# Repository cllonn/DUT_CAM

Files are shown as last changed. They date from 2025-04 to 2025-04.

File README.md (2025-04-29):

# DUT_CAM Camera Board Project
PCB designed to interface a camera module with the Atlas board to provide standalone testing for future design

## Project Overview
This board is a camera testing board that uses an OV2640 camera signals to an ESP32-S3, adds microSD storage, and includes USB-C power input with LDOs. Mainly used as a verificationnn board for later Atlas integration.

## Features
- **USB-C Power Input**: 5 V via USB-C connector
- **Power Regulation**:
  - 3.3 V LDO for ESP32-S3 and camera core
  - 2.8 V LDO for camera I/O
  - 1.2 V LDO for camera I/O
- **Camera Sensor Interface**:
  - 24-pin FPC footprint for OV2640
  - I²C (SDA/SCL) and parallel data bus (D0–D7) breakout
- **Microcontroller Footprint**: ESP32-S3-WROOM-1-N8R8 for on-board firmware testing
- **MicroSD Card Slot**: Store captured images or log data locally

## Block Diagram
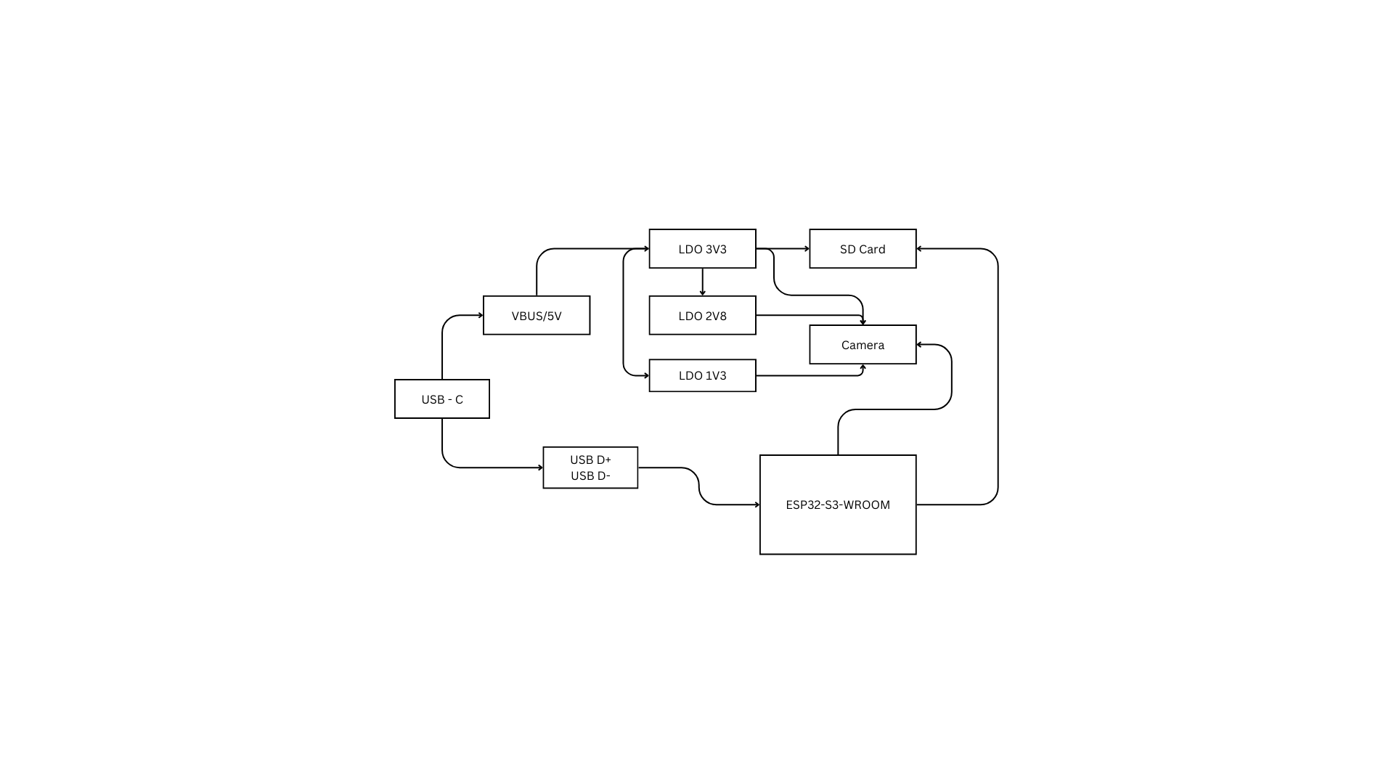
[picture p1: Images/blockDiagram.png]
Block Diagram


## Circuit Schematic
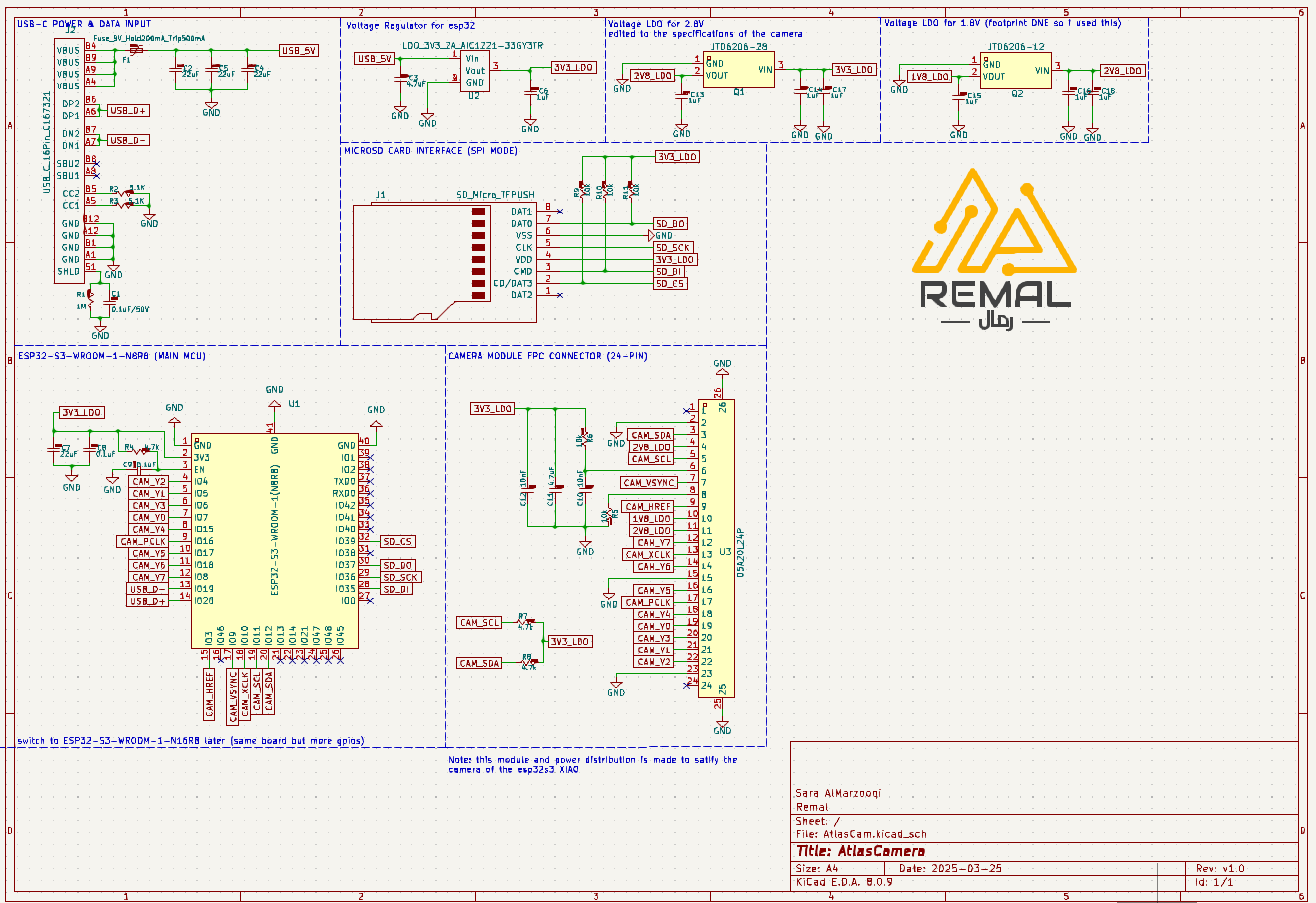
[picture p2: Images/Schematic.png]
Circuit Schematic


## PCB Layout
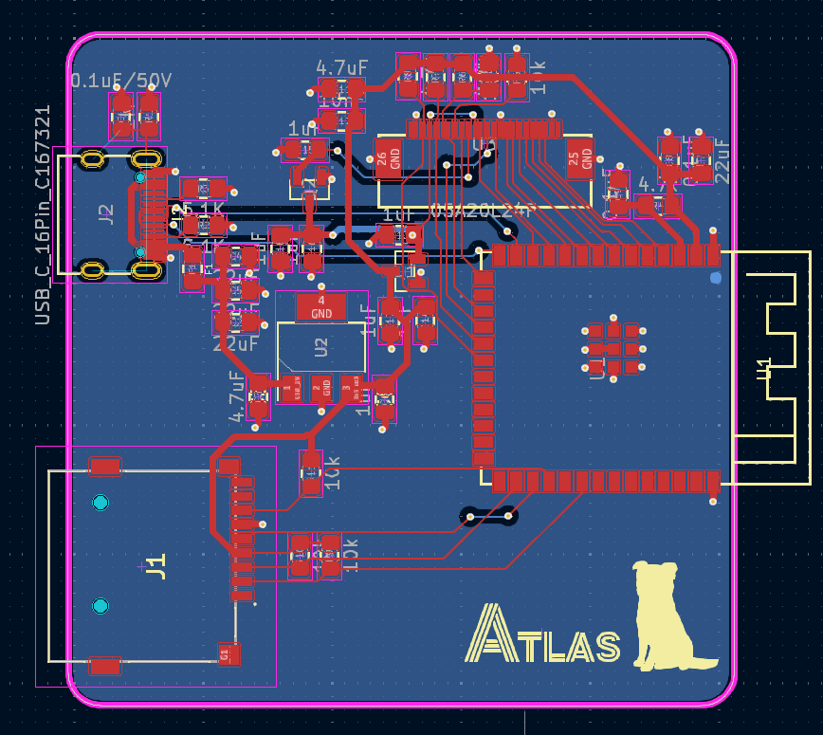
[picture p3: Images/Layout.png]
PCB Layout


## Usage
1. Insert a microSD card into the slot.
2. Flash and run code written for the board.
3. Open the serial monitor and note the IP address the board prints.
4. In your web browser, navigate to `http://<board_ip>/`.
5. Enjoy the live video stream.

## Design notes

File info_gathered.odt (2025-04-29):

Upgrading Atlas to feature a camera

Microcontroller chosen: ESP32-S3-WROOM-1-N8R8

Datasheet: https://www.lcsc.com/datasheet/lcsc_datasheet_2411121101_Espressif-Systems-ESP32-S3-WROOM-1-N8R8_C2913201.pdf

XIAO-ESP32S3 Sense:

Link to ebook: https://mjrovai.github.io/XIAO_Big_Power_Small_Board-ebook/

Specification:

Processor: ESP32-S3R8, Xtensa LX7 dual-core, 32-bit processor that operates at up to 240 Mhz

Wireless: Complete 2.4GHz Wi-Fi subsystem; BLE: Bluetooth 5.0, Bluetooth mesh

Built-in Sensors: OV2640 camera sensor for 1600*1200; Digital microphone

Memory: On-chip 8M PSRAM & 8MB Flash; Onboard SD Card Slot, supporting 32GB FAT

Interface: 1x UART, 1x IIC, 1x IIS, 1x SPI, 11x GPIOs (PWM), 9x ADC, 1x User LED, 1x Charge LED, 1x B2B Connector (with 2 additional GPIOs), 1x Reset button, 1x Boot button

Dimentions: 21 x 17.8 x 15mm (with expansion board)

Power:- Input voltage (Type-C): 5V; Input voltage (BAT): 4.2V

- Circuit operating Voltage (ready to operate):
- Type-C: 5V@38.3mA
- BAT: 3.8V@43.2mA (with expansion board)

- Webcam Web application:
- Type-C:
- Average power consumption: 5V/138mA
- Photo moment: 5V/341mA
- Battery:
- Average power consumption: 3.8V/154mA
- Photo moment: 3.8V/304mA

- Microphone recording & SD card writing:
- Type-C:
- Average power consumption: 5V/46.5mA
- Peak power consumption: 5V/89.6mA
- Battery:
- Average power consumption: 3.8V/54.4mA
- Peak power consumption: 3.8V/108mA

- Charging battery current: 100mA

Low Power Consumption Model:

- Without any peripherals:
- Modem-sleep Model: 3.8V/25.5 mA
- Light-sleep Model: 3.8V/2.4 mA
- Deep Sleep Model: 3.8V/63.768 μA
- Connect the camera:
- Modem-sleep Model: 3.8V/44.57 mA
- Light-sleep Model: 3.8V/5.47 mA
- Deep Sleep Model: 3.8V/3.00 mA
- Connecting an SD Card:
- Modem-sleep Model: 3.8V/32.8 mA
- Light-sleep Model: 3.8V/3.48 mA
- Deep Sleep Model: 3.8V/1.08 mA
- Simultaneously connect the camera and the SD card:
- Modem-sleep Model: 3.8V/55.72 mA
- Light-sleep Model: 3.8V/6.56 mA
- Deep Sleep Model: 3.8V/3.98 mA

Wi-Fi Enabled Power Consumptionnn: ~110 mA

BLE Enabled Power Connnnnnnsumptionnnnnnnnnnn: ~102 mA

Pins needed for camera: 14

- 1 XMCLK

- 8 Y#

- 1 PCLK

- 2 I2C (SDA, SCL)

- 1 VSYNC

- 1 HREF

Pins needed f MicroSD: 4 -> Atlas already has MicroSD slot that is counted for

Pins needed for MIC: 2 -> We dont want a mic do ignore.

Schematic and Layout of XIAO-ESP32-S3 Sense (https://wiki.seeedstudio.com/xiao_esp32s3_getting_started/#for-seeed-studio-xiao-esp32s3-sense)

- [PDF] Seeed Studio XIAO ESP32S3 Sense Schematic (https://files.seeedstudio.com/wiki/SeeedStudio-XIAO-ESP32S3/res/XIAO_ESP32S3_ExpBoard_v1.0_SCH.pdf)
- [Ebook] XIAO: Big Power, Small Board Mastering Arduino and TinyML (https://mjrovai.github.io/XIAO_Big_Power_Small_Board-ebook/)
- [ZIP] Seeed Studio XIAO ESP32S3 Sense KiCAD Libraries (https://files.seeedstudio.com/wiki/SeeedStudio-XIAO-ESP32S3/res/Seeeduino-xiao-ESP32S3-KiCAD-Library.zip)
- [ZIP] Seeed Studio XIAO ESP32S3 Sense Eagle Libraries (https://files.seeedstudio.com/wiki/SeeedStudio-XIAO-ESP32S3/res/XIAO_ESP32S3_ExpBoard_v1.0_SCH&PCB_230324.zip)
- [DXF] Seeed Studio XIAO ESP32S3 Sense Dimension in DXF (top) (https://files.seeedstudio.com/wiki/SeeedStudio-XIAO-ESP32S3/res/XIAO_ESP32S3_ExpBoard_v1.0_top.dxf)
- [DXF] Seeed Studio XIAO ESP32S3 Sense Dimension in DXF (bottom) (https://files.seeedstudio.com/wiki/SeeedStudio-XIAO-ESP32S3/res/XIAO_ESP32S3_ExpBoard_v1.0_bot.dxf)
- [ZIP] Seeed Studio XIAO ESP32S3 Sense Factory firmware (https://files.seeedstudio.com/wiki/SeeedStudio-XIAO-ESP32S3/res/XIAO-ESP32S3-Sense-firmware-20240814.zip)
- [XLSX] Seeed Studio XIAO ESP32S3 Sense pinout sheet (https://files.seeedstudio.com/wiki/SeeedStudio-XIAO-ESP32S3/res/XIAO_ESP32S3_Sense_Pinout.xlsx)
- [STEP] Seeed Studio XIAO ESP32S3 Sense 3D Model (https://files.seeedstudio.com/wiki/SeeedStudio-XIAO-ESP32S3/res/seeed-studio-xiao-esp32s3-sense-3d_model.zip)
- 🔗 [Kicad] Seeed Studio XIAO ESP32S3 Sense FootPrint (https://github.com/Seeed-Studio/OPL_Kicad_Library/tree/master/Seeed%20Studio%20XIAO%20Series%20Library)

And for the bottom layer (XIAO ESP32-S3) (https://wiki.seeedstudio.com/xiao_esp32s3_getting_started/#for-seeed-studio-xiao-esp32s3)

- [PDF] Seeed Studio XIAO ESP32S3 Schematic (https://files.seeedstudio.com/wiki/SeeedStudio-XIAO-ESP32S3/res/XIAO_ESP32S3_SCH_v1.2.pdf)
- [ZIP] Seeed Studio XIAO ESP32S3 Eagle Libraries (https://files.seeedstudio.com/wiki/SeeedStudio-XIAO-ESP32S3/res/XIAO_ESP32S3_v1.1_SCH&PCB_230327.zip)
- [DXF] Seeed Studio XIAO ESP32S3 Dimension in DXF (https://files.seeedstudio.com/wiki/SeeedStudio-XIAO-ESP32S3/res/XIAO_ESP32S3_v1.1_Dimensioning.dxf)
- [LBR] Seeed Studio XIAO ESP32S3 Eagle footprint (https://files.seeedstudio.com/wiki/SeeedStudio-XIAO-ESP32S3/res/Seeed-Studio-XIAO-ESP32S3-footprint-eagle.lbr)
- [ZIP] Seeed Studio XIAO ESP32S3 Factory firmware (https://files.seeedstudio.com/wiki/SeeedStudio-XIAO-ESP32S3/res/XIAO-ESP32S3-firmware-20240814.zip)
- [XLSX] Seeed Studio XIAO ESP32S3 pinout sheet (https://files.seeedstudio.com/wiki/SeeedStudio-XIAO-ESP32S3/res/XIAO_ESP32S3_Sense_Pinout.xlsx)
- [STEP] Seeed Studio XIAO ESP32S3 3D Model (https://files.seeedstudio.com/wiki/SeeedStudio-XIAO-ESP32S3/res/seeed-studio-xiao-esp32s3-3d_model.zip)
- [ZIP] Seeed Studio XIAO ESP32S3 Certification files (https://files.seeedstudio.com/wiki/SeeedStudio-XIAO-ESP32S3/res/XIAO_ESP32S3_Certification.zip)
- 🔗 [Kicad] Seeed Studio XIAO ESP32S3 FootPrint (https://github.com/Seeed-Studio/OPL_Kicad_Library/tree/master/Seeed%20Studio%20XIAO%20Series%20Library)

ESP32_CAM_S

Link to schematic: file:///home/sara/Desktop/CameraResearch/esp32_cam_sch.pdf

Pins needed for camera: 14

- 8 Y# -> 8-bit parallel pixel data

- 1 MCLK ->External clock input from ESP32 to run its internal logic

- 1 PCLK ->Pixel clock. Tells ESP32 when to read the D0–D7 pins

- 2 I2C (SDA, Sck) -> SDA:Used to configure camera settings (brightness, etc)

-> SCL:Clock line for camera configuration

- 1 VSYNC ->Vertical sync

- 1 HSYNC ->Horizontal reference

Pins needed f MicroSD: 4 -> Atlas already has MicroSD slot that is counted for

[VSYNC] -> Start of Frame

[HREF] -> Start of Row

[PCLK] -> New Byte on D0-D7:

D0-D7: 10010110

D0-D7: 11000110

[HREF] Ends -> End of Row

[VSYNC] Ends -> End of Frame

Comparision list

Feature | XIAO ESP32S3 | AI-Thinker ESP32-CAM
Chip | ESP32-S3R8 (dual-core LX7) | ESP32 (dual-core LX6)
Flash Memory | 8MB | 4MB
PSRAM | 8MB | 4MB
Camera Sensor | OV2640 built-in (on expansion board) | OV2640 built-in
Max Camera Resolution | 1600×1200 (UXGA) | 1600×1200 (UXGA)
SD Card Slot | Onboard (up to 32GB FAT) | Built-in
Microphone | Digital mic onboard (I2S) | Not included
Battery Support | Contains mountable battery space and recharge | Vin, gnd – no recharge
Wi-Fi | Wi-Fi 4 (802.11 b/g/n) | Wi-Fi 4 (802.11 b/g/n/e/i)
Bluetooth | Bluetooth 5.0 + Mesh | Bluetooth 4.2
USB | Native USB-C (no programmer needed) | Requires external USB-to-Serial adapter
GPIOs (usable) | ~11 GPIOs (PWM capable), +2 via B2B connector | 9 GPIOs (shared with camera/sd)
Programming & Debugging | Simple: USB-C | Requires external programmer
Camera Interface | Native parallel (LCD_CAM peripheral) | GPIO-based (bit-banged style)
Power Supply | 5V via USB-C or 4.2V battery | 5V via header
Wi-Fi ON | ~110mA | ~180mA wif flash OFF
Camera + SD (Photo Moment) | 304–341mA peak | 310mA with flash ON
Deep Sleep (no peripherals) | 63.8 µA | ~6mA
Camera + SD (Deep Sleep) | ~4mA | Not specified but likely ~6–10mA
Charging Current (USB-C) | 100mA | Not built-in

Camera is not available at the lcsc but i found it on alibaba

https://www.alibaba.com/product-detail/Mini-OV2640-2-Million-Pixel-Wide_1601278159929.html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

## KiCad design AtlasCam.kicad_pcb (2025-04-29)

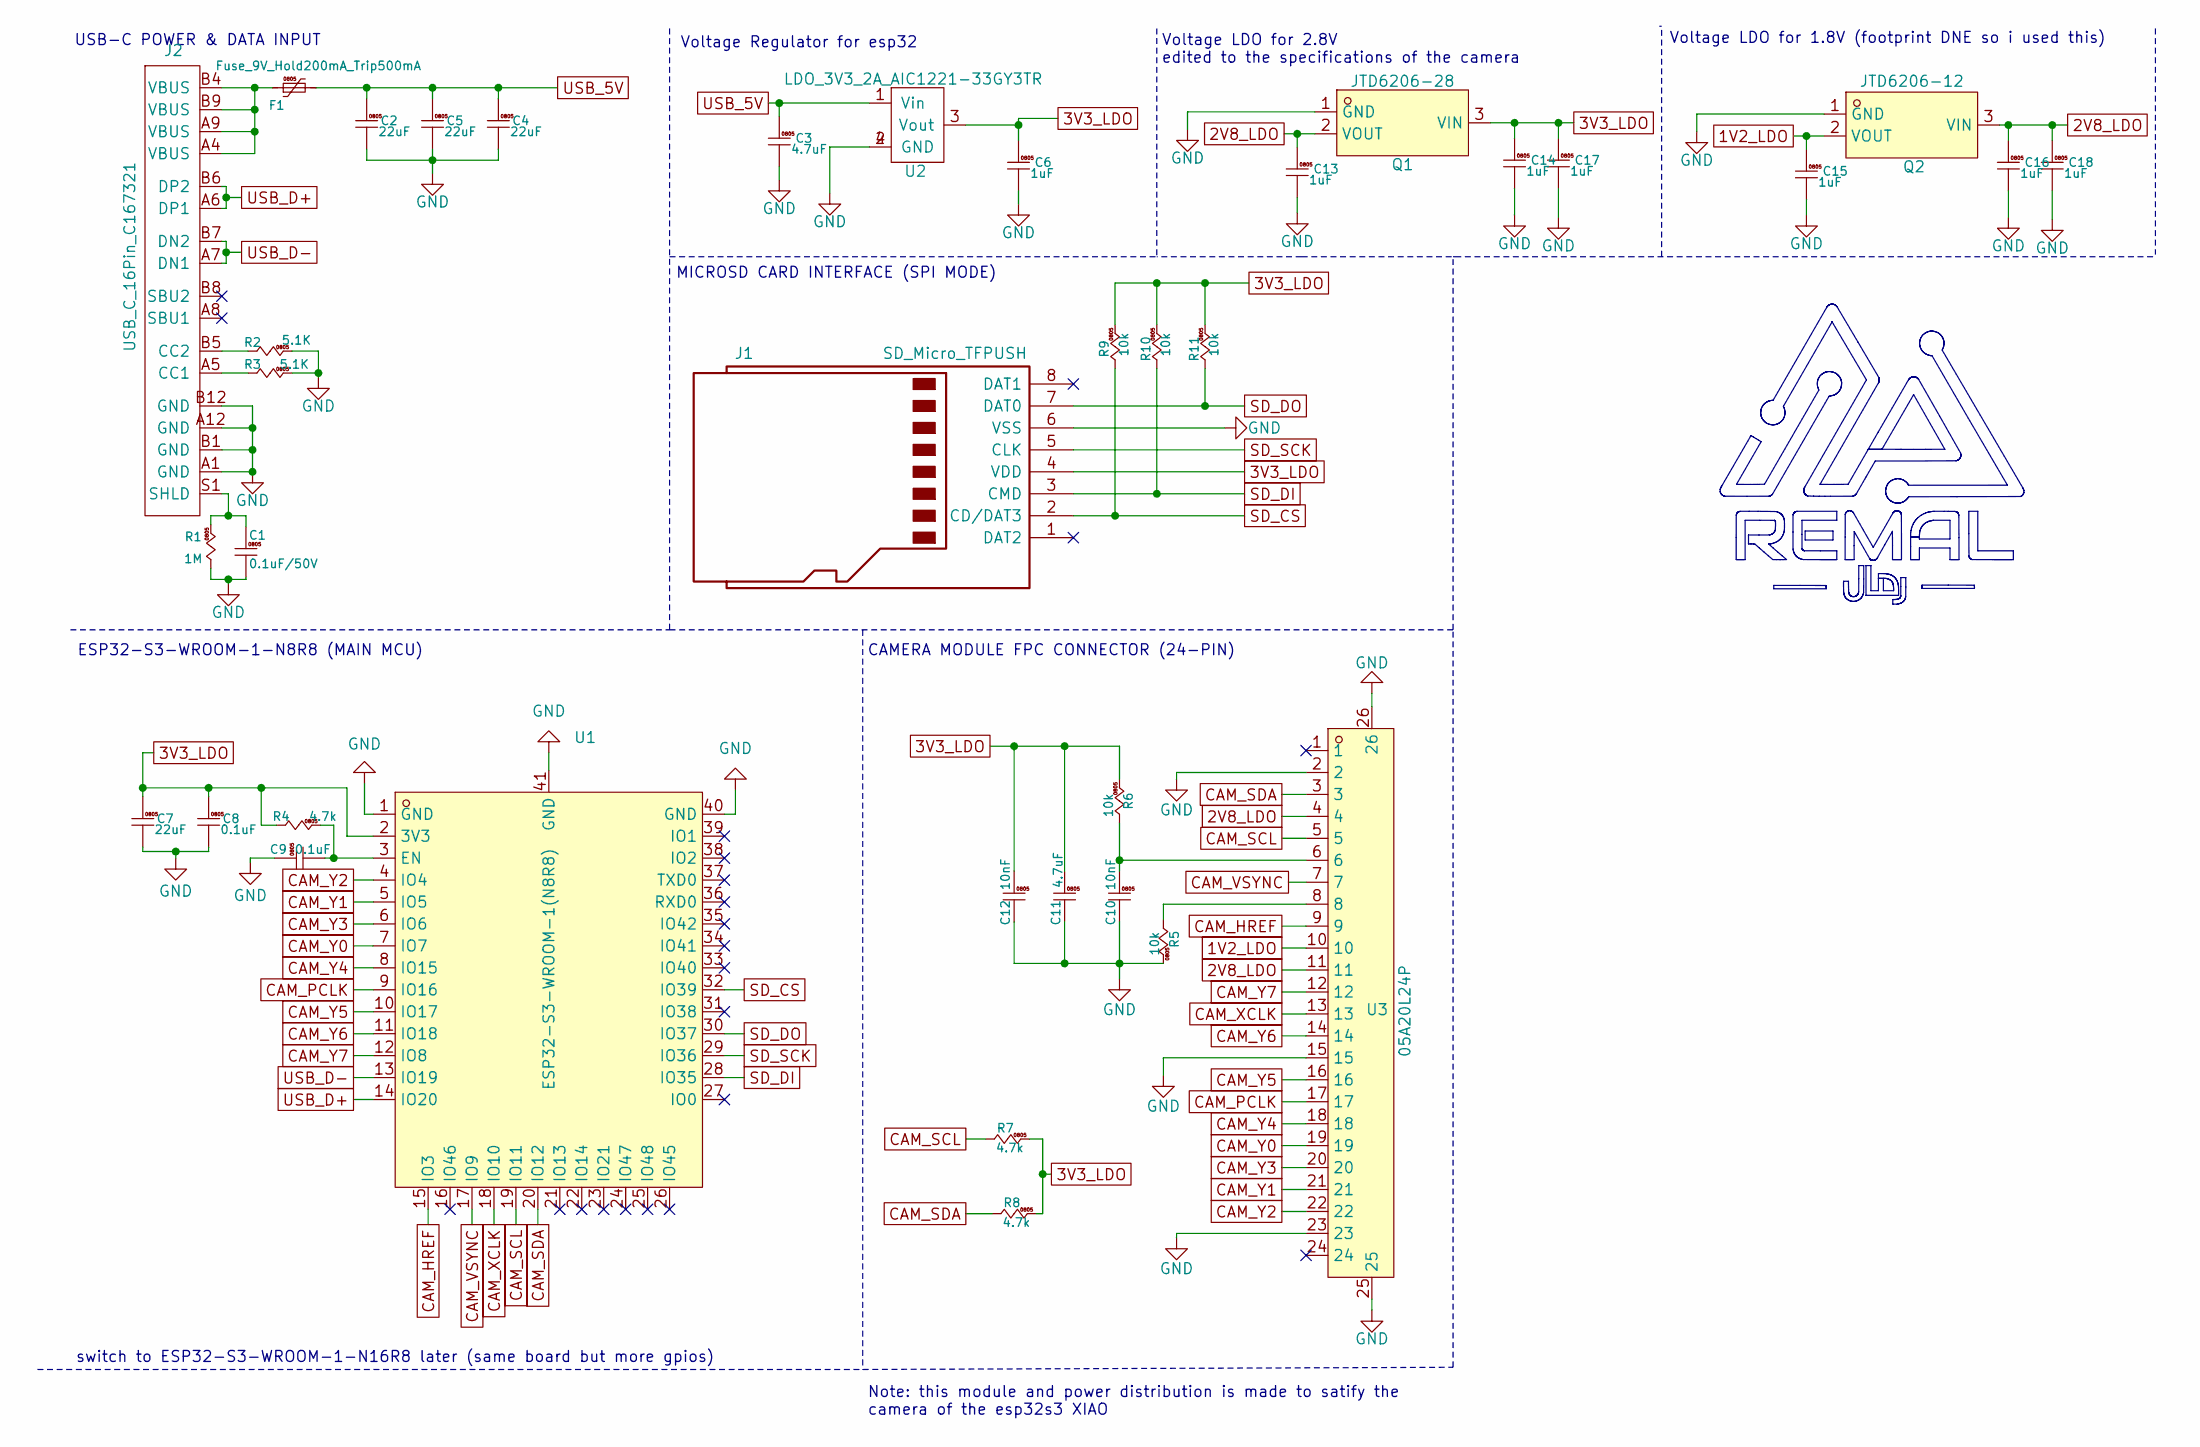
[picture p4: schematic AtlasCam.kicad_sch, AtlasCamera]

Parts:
C1: 0.1uF/50V; C_0805_2012m
C2, C4, C5, C7: 22uF; C_0805_2012m
C3, C11: 4.7uF; C_0805_2012m
C6, C13, C14, C15, C16, C17, C18: 1uF; C_0805_2012m
C8, C9: 0.1uF; C_0805_2012m
C10, C12: 10nF; C_0805_2012m
F1: Fuse_9V_Hold200mA_Trip500mA; Fuse_0805_2012m
J1: SD_Micro_TFPUSH
J2: USB_C_16Pin_C167321; USB_C_16Pin_918-418K2023S40001
Q1: JTD6206-28; SOT-23-3_L2.9-W1.3-P1.90-LS2.4-BR; LCSC Part C42443426
Q2: JTD6206-12; SOT-23-3_L2.9-W1.3-P1.90-LS2.4-BR; LCSC Part C42443426
R1: 1M; R_0805_2012m
R2, R3: 5.1K; R_0805_2012m
R4, R7, R8: 4.7k; R_0805_2012m
R5, R6, R9, R10, R11: 10k; R_0805_2012m
U1: ESP32-S3-WROOM-1(N8R8); WIRELM-SMD_ESP32-S3-WROOM-1; LCSC Part C2913201
U2: LDO_3V3_2A_AIC1221-33GY3TR; SOT-223
U3: 05A20L24P; FPC-SMD_24P-P0.50_05A20L24P; LCSC Part C5362158

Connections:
1V2_LDO: C15.1, Q2.2 (VOUT), U3.10
2V8_LDO: C13.1, C16.1, C18.1, Q1.2 (VOUT), Q2.3 (VIN), U3.4, U3.11
3V3_LDO: C6.1, C7.1, C8.1, C11.1, C12.1, C14.1, C17.1, J1.4 (VDD), Q1.3 (VIN), R4.1, R6.2, R7.2, R8.2, R9.2, R10.2, R11.2, U1.2 (3V3), U2.3 (Vout)
CAM_HREF: U1.15 (IO3), U3.9
CAM_PCLK: U1.9 (IO16), U3.17
CAM_SCL: R7.1, U1.19 (IO11), U3.5
CAM_SDA: R8.1, U1.20 (IO12), U3.3
CAM_VSYNC: U1.17 (IO9), U3.7
CAM_XCLK: U1.18 (IO10), U3.13
CAM_Y0: U1.7 (IO7), U3.19
CAM_Y1: U1.5 (IO5), U3.21
CAM_Y2: U1.4 (IO4), U3.22
CAM_Y3: U1.6 (IO6), U3.20
CAM_Y4: U1.8 (IO15), U3.18
CAM_Y5: U1.10 (IO17), U3.16
CAM_Y6: U1.11 (IO18), U3.14
CAM_Y7: U1.12 (IO8), U3.12
GND: C1.2, C2.2, C3.2, C4.2, C5.2, C6.2, C7.2, C8.2, C9.1, C10.2, C11.2, C12.2, C13.2, C14.2, C15.2, C16.2, C17.2, C18.2, J1.6 (VSS), J2.A1 (GND), J2.A12 (GND), J2.B1 (GND), J2.B12 (GND), Q1.1 (GND), Q2.1 (GND), R1.1, R2.2, R3.2, R5.2, U1.1 (GND), U1.40 (GND), U1.41 (GND), U2.2 (GND), U2.4 (GND), U3.2, U3.15, U3.23, U3.25, U3.26
unnamed: C10.1, R6.1, U3.6
unnamed: F1.1, J2.A4 (VBUS), J2.A9 (VBUS), J2.B4 (VBUS), J2.B9 (VBUS)
unnamed: J2.A5 (CC1), R3.1
unnamed: J2.B5 (CC2), R2.1
unnamed: C1.1, J2.S1 (SHLD), R1.2
unnamed: R5.1, U3.8
unnamed: C9.2, R4.2, U1.3 (EN)
SD_CS: J1.2 (CD/DAT3), R9.1, U1.32 (IO39)
SD_DI: J1.3 (CMD), R10.1, U1.28 (IO35)
SD_DO: J1.7 (DAT0), R11.1, U1.30 (IO37)
SD_SCK: J1.5 (CLK), U1.29 (IO36)
USB_5V: C2.1, C3.1, C4.1, C5.1, F1.2, U2.1 (Vin)
USB_D+: J2.A6 (DP1), J2.B6 (DP2), U1.14 (IO20)
USB_D-: J2.A7 (DN1), J2.B7 (DN2), U1.13 (IO19)

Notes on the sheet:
CAMERA MODULE FPC CONNECTOR (24-PIN)
Voltage LDO for 1.8V (footprint DNE so i used this)
MICROSD CARD INTERFACE (SPI MODE)
switch to ESP32-S3-WROOM-1-N16R8 later (same board but more gpios)
Voltage LDO for 2.8V edited to the specifications of the camera
USB-C POWER & DATA INPUT
Note: this module and power distribution is made to satify the camera of the esp32s3 XIAO
Voltage Regulator for esp32
ESP32-S3-WROOM-1-N8R8 (MAIN MCU)

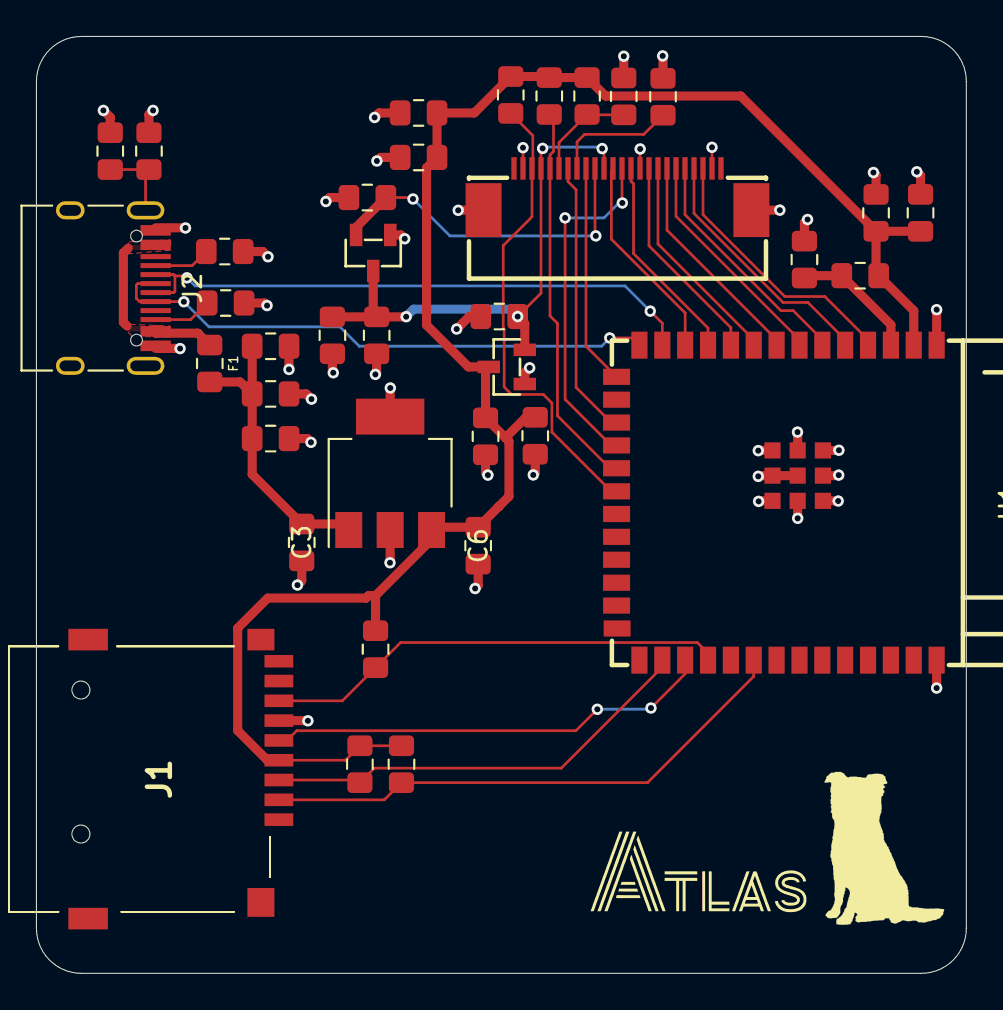
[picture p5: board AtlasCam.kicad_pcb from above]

Board: 2 copper layers, 51.7 x 52.0 mm, 37 parts (0 on the bottom side), 32 nets.

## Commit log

2025-04-21 First Draft: b4 verification
    [AtlasCam.kicad_pcb, AtlasCam.kicad_sch]
2025-04-29 First Draft: routiing, pulled D+/D- lines together, SD closer to edge
    [AtlasCam.kicad_pcb, AtlasCam.kicad_sch]
2025-04-29 Updated READDME: better description of board
2025-04-29 Final Updates: pulled D-/D+ closer, moved SD Slot to edge, Verified design
    [AtlasCam.kicad_pcb, AtlasCam.kicad_sch]
